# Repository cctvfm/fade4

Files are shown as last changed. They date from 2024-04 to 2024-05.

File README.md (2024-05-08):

# fade4
A performance MIDI and CV controller based on SAMD21G

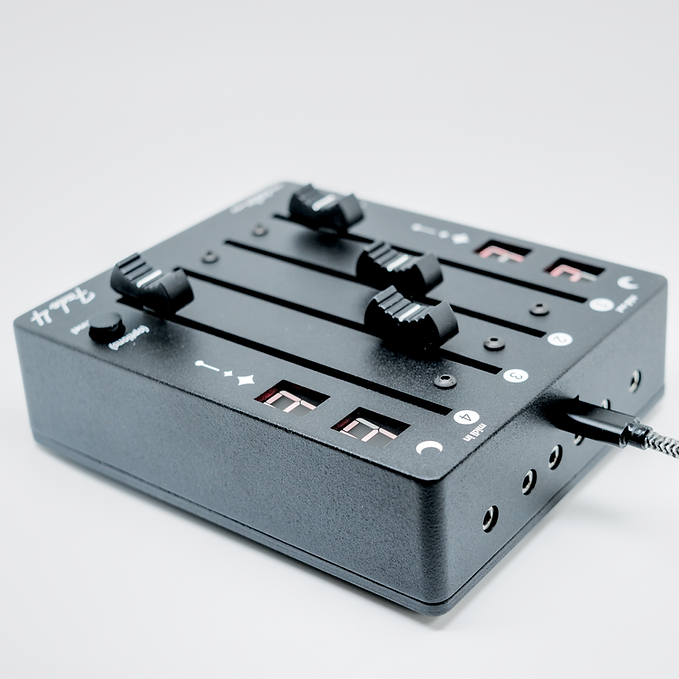
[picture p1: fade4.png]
Fade 4


Fade 4 runs on an Atmel SAMD21G microcontroller running the Feather M0 Bootloader. This allows Fade 4 to be developed on using the Arduino programming environment, and make use of Arduino libraries.

The SAMD21G handles all USB communication while using it's internal ADCs to read the positions of the faders. Each fader is connected between 0V and 3.3V, with the wiper providing a voltage between 0V and 3.3V. An opamp is used to multiply this voltage by 1.5x to provide 0 to 5V to the CV outputs. The fader position is sampled through Responsive Analog Read to smooth out any jumpiness in the measurement.

MIDI is handled using the Forty Seven Effects MIDI Library, making sending MIDI and USB MIDI the simplest part of this device.

The 7 segment LED displays are of the common cathode type, meaning the 7 LEDs in the character have their anodes broken out to individual pins, while the cathodes are grouped together into one pin. I use a 2N3904 transistor connected to this cathode pin to enable the digit, allowing the 4 digits to share character pins, as long as each has its own transistor and cathode pin. 

These displays need to be enabled one at a time, and using persistence of vision it appears that the 4 digits are on all the time. The timing of these characters is handled by TC3, triggering an interrupt to turn the current LED charactor off, reconfigure the pins, and turn the next one on.

A second timer, TC0, is used to generate a PWM signal on the 4 cathode transistor pins. This PWM signal can be changed to adjust the brightness of the display from 0 to 100%.

_FIRMWARE UPDATE_

1) Download the .UF2 file for the new firmware

2) Remove the 4 screws on the bottom of Fade 4, and remove the cover.

3) Plug Fade 4 into your computer using  a USB-C cable. Mac or Windows or Linux, doesn't matter. It will show up as a MIDI device named "Fade 4".

4) Double tap the button on the PCB marked "RESET". Two quick presses. A USB drive will appear on your computer, labelled "FEATHER" or "FEATHERBOOT"

5) Copy and paste the UF2 file into the USB drive. If prompted to overwrite, select YES.

6) Unplug, and reinstall the bottom cover. The firmware has been updated.

_HACKING_

You just need the .ino file in a folder named the same as it. Arduino or Arduino IDE, but you will need the following packages:

Adafruit SAMD Board Package
Flash Storage
Responsive Analog Read
MIDI

All firmware updates can be done over the USB C port. The 4 pin header is just for initial bootloader burn using an SWD programmer.

*November 2023:* 5 units built for testing. These are V1.0 units. They have an issue where the ADC is referenced to 5V and not 3.3V, so depending on USB power supply, the faders may not reach all the way to 127. fade4.ino.feather_m0-MAX975.uf2 provided as a fix for these units.

*April 15 2024:* Initial kit run. V1.1 released, fixes above issue. Build guide published to cctv.fm/fade4. Shipped with V1.1 preflashed.

*April 17 2023:* Bug fix, channels via TRS do not match channels via USB. Due to USB library counting channels from 0 and MIDI library counting from 1.

*May 8 2024:* Chris found a bug causing Program Changes to not function at all on V12, added bounds checking to message types.

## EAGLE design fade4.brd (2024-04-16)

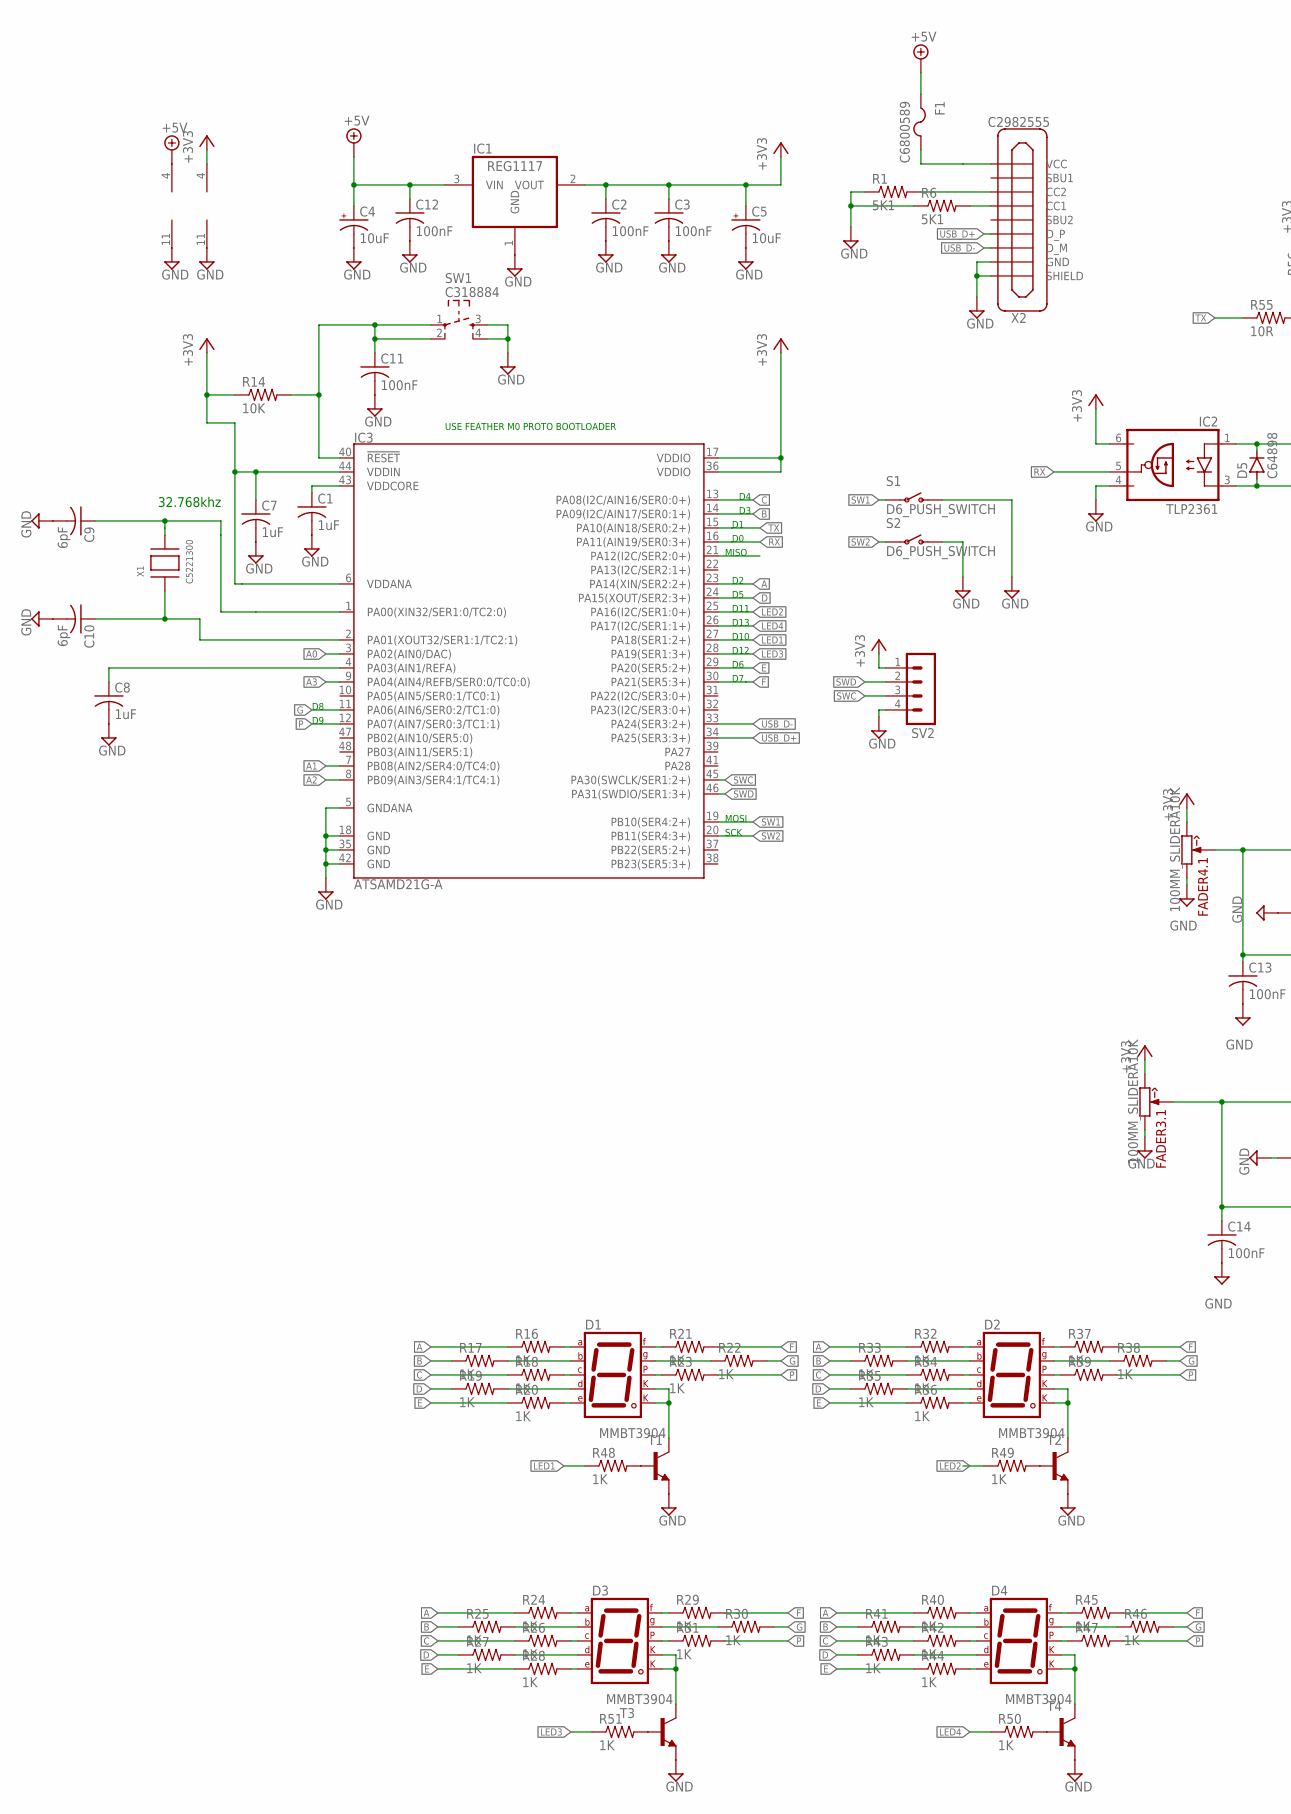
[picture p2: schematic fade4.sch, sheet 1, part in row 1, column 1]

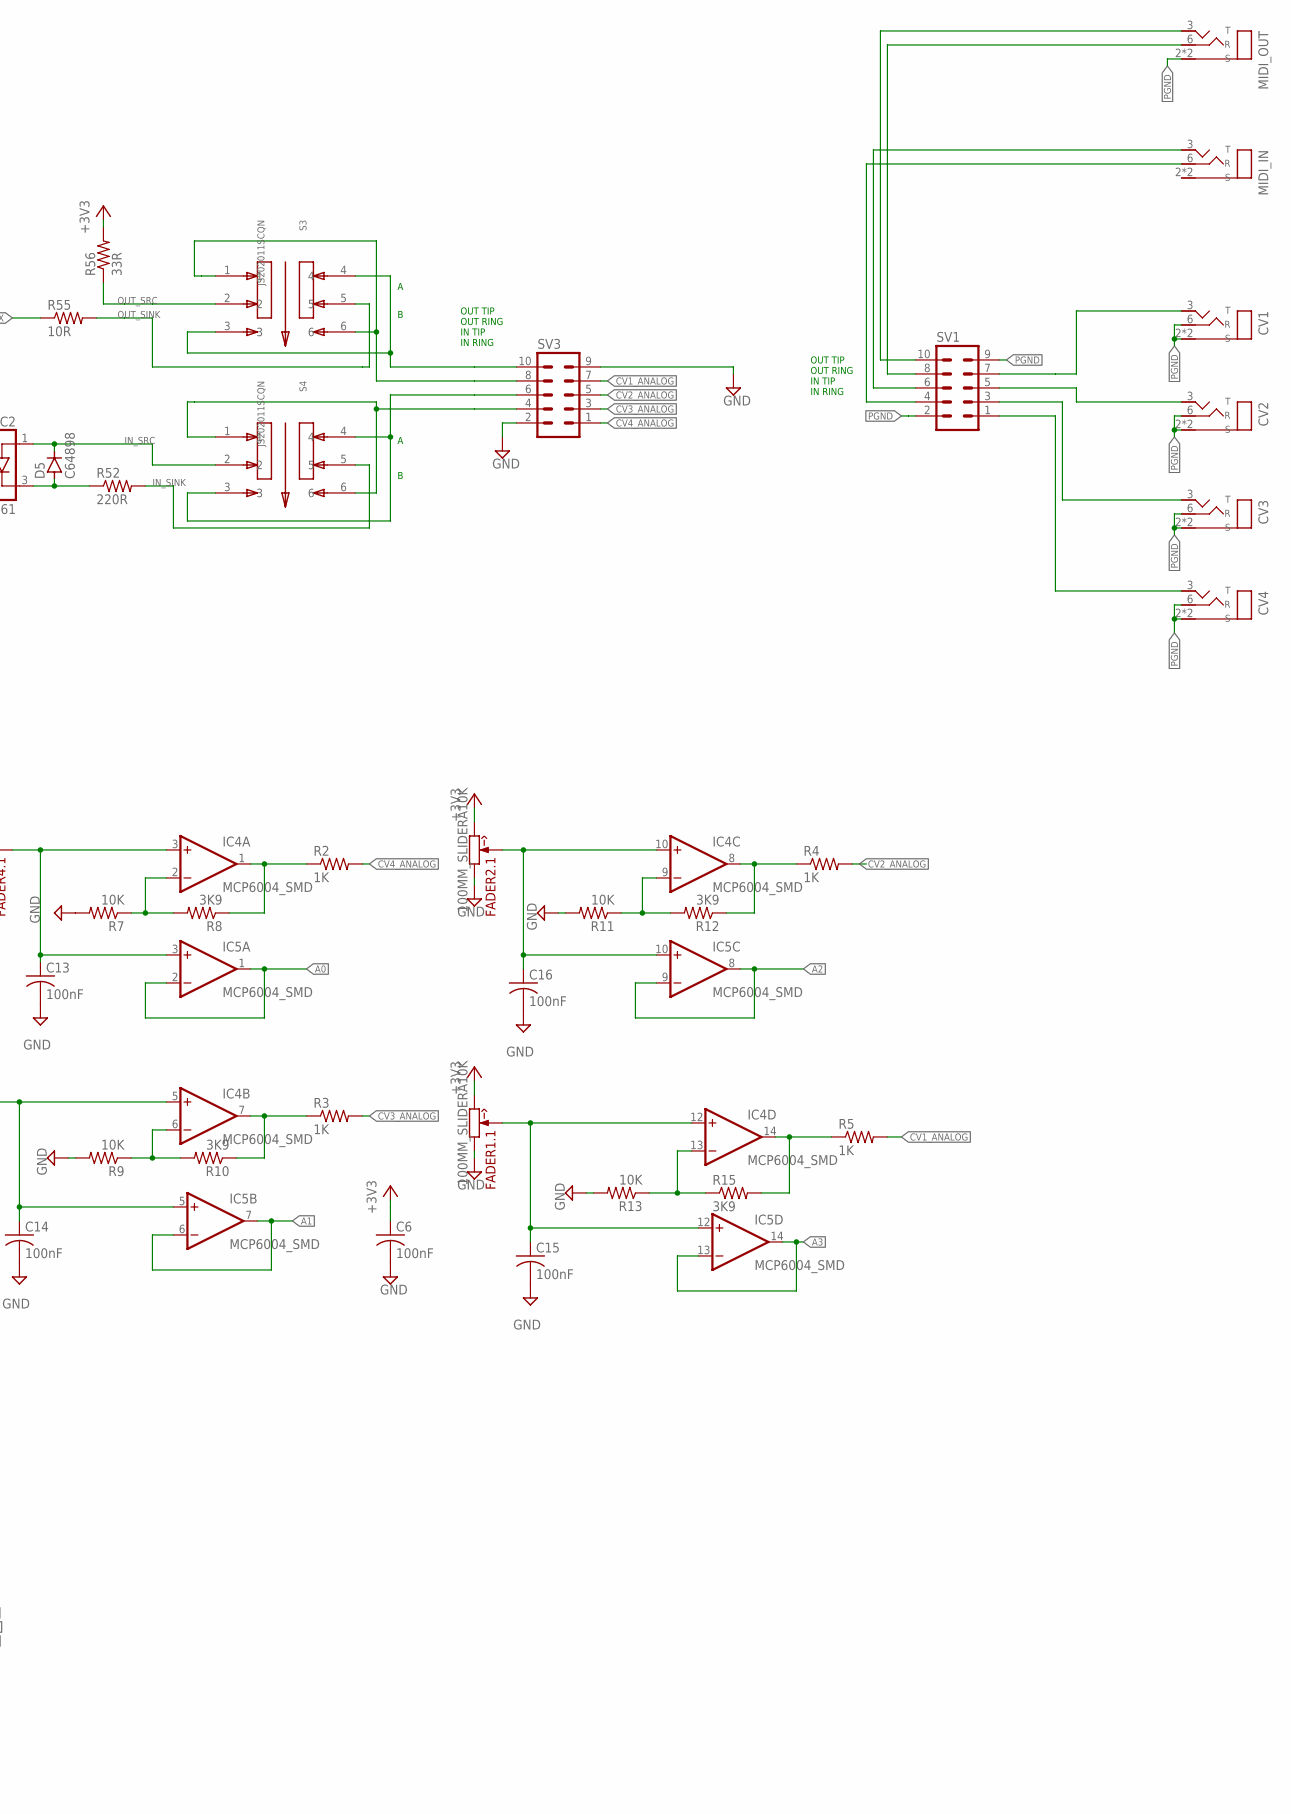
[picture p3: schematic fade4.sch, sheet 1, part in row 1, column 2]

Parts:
C1, C7, C8: 1uF; C0603K
C2, C3, C6, C11, C12, C13, C14, C15, C16: 100nF; C0603K
C4, C5: 10uF; A/3216-18R
C9, C10: 6pF; C0603K
CV1, CV2, CV3, CV4: C725772
D1, D2, D3, D4: 7SEG-CK; 7SEG-13
D5: C64898; SOD123
F1: C6800589; R1206
FADER1, FADER2, FADER3, FADER4: 100MM_SLIDERA10K; 100MM-SLIDER
IC1: REG1117; SOT223
IC2: TLP2361; SOIC-5
IC3: ATSAMD21G-A; TQFP-48
IC4, IC5: MCP6004_SMD; SO14
MIDI_IN: C725772
MIDI_OUT: C725772
R1, R6: 5K1; R0603
R2, R3, R4, R5, R16, R17, R18, R19, R20, R21, R22, R23, R24, R25, R26, R27, R28, R29, R30, R31, R32, R33, R34, R35, R36, R37, R38, R39, R40, R41, R42, R43, R44, R45, R46, R47, R48, R49, R50, R51: 1K; R0603
R7, R9, R11, R13, R14: 10K; R0603
R8, R10, R12, R15: 3K9; R0603
R52: 220R; R0603
R55: 10R; R1206
R56: 33R; R1206
S1, S2: D6_PUSH_SWITCH
S3, S4: JS202011SCQN; SW_JS202011SCQN
SV1, SV3: MA05-2
SV2: MA04-1
SW1: C318884; SW_TACT_SMALL
T1, T2, T3, T4: MMBT3904; SOT23-BEC
X1: C5221300; XTAL3215
X2: C2982555

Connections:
+3V3: C2.1, C3.1, C5.+, C6.1, C7.1, FADER1.A3 (CW), FADER2.A3 (CW), FADER3.A3 (CW), FADER4.A3 (CW), IC1.2 (VOUT), IC2.6 (VCC), IC3.6 (VDDANA), IC3.17 (VDDIO), IC3.36 (VDDIO), IC3.44 (VDDIN), IC5.4 (V+), R14.1, R56.2, SV2.1
+5V: C4.+, C12.1, F1.1, IC1.3 (VIN), IC4.4 (V+)
A: IC3.23 (PA14(XIN/SER2:2+)), R16.1, R24.1, R32.1, R40.1
A0: IC3.3 (PA02(AIN0/DAC)), IC5.1 (OUT), IC5.2 (-IN)
A1: IC3.7 (PB08(AIN2/SER4:0/TC4:0)), IC5.6 (-IN), IC5.7 (OUT)
A2: IC3.8 (PB09(AIN3/SER4:1/TC4:1)), IC5.8 (OUT), IC5.9 (-IN)
A3: IC3.9 (PA04(AIN4/REFB/SER0:0/TC0:0)), IC5.13 (-IN), IC5.14 (OUT)
B: IC3.14 (PA09(I2C/AIN17/SER0:1+)), R17.1, R25.1, R33.1, R41.1
C: IC3.13 (PA08(I2C/AIN16/SER0:0+)), R18.1, R26.1, R34.1, R42.1
CV1_ANALOG: R5.2, SV3.7
CV2_ANALOG: R4.2, SV3.5
CV3_ANALOG: R3.2, SV3.3
CV4_ANALOG: R2.2, SV3.1
D: IC3.24 (PA15(XOUT/SER2:3+)), R19.1, R27.1, R35.1, R43.1
E: IC3.29 (PA20(SER5:2+)), R20.1, R28.1, R36.1, R44.1
F: IC3.30 (PA21(SER5:3+)), R21.2, R29.2, R37.2, R45.2
G: IC3.11 (PA06(AIN6/SER0:2/TC1:0)), R22.2, R30.2, R38.2, R46.2
GND: C1.2, C2.2, C3.2, C4.-, C5.-, C6.2, C7.2, C8.2, C9.2, C10.2, C11.2, C12.2, C13.2, C14.2, C15.2, C16.2, FADER1.A1 (CCW), FADER2.A1 (CCW), FADER3.A1 (CCW), FADER4.A1 (CCW), IC1.1 (GND), IC2.4 (GND), IC3.5 (GNDANA), IC3.18 (GND), IC3.35 (GND), IC3.42 (GND), IC4.11 (V-), IC5.11 (V-), R1.1, R6.1, R7.2, R9.2, R11.2, R13.2, S1.P$1 (O), S1.P$2 (O), S2.P$1 (O), S2.P$2 (O), SV2.4, SV3.2, SV3.9, SW1.3, SW1.4, T1.E, T2.E, T3.E, T4.E, X2.A12B1 (GND), X2.B12A1 (GND), X2.SHIELD1 (SHIELD), X2.SHIELD2 (SHIELD), X2.SHIELD3 (SHIELD), X2.SHIELD4 (SHIELD)
IN_RING: S4.1, S4.6, SV3.4
IN_SINK: R52.2, S4.5
IN_SRC: D5.1 (C), IC2.1 (A), S4.2
IN_TIP: S4.3, S4.4, SV3.6
LED1: IC3.27 (PA18(SER1:2+)), R48.1
LED2: IC3.25 (PA16(I2C/SER1:0+)), R49.1
LED3: IC3.28 (PA19(SER1:3+)), R51.1
LED4: IC3.26 (PA17(I2C/SER1:1+)), R50.1
unnamed: R6.2, X2.A5 (CC1)
unnamed: R1.2, X2.B5 (CC2)
unnamed: C1.1, IC3.43 (VDDCORE)
unnamed: F1.2, X2.A9B4 (VCC), X2.B9A4 (VCC)
unnamed: C13.1, FADER4.A2 (W), IC4.3 (+IN), IC5.3 (+IN)
unnamed: C14.1, FADER3.A2 (W), IC4.5 (+IN), IC5.5 (+IN)
unnamed: C16.1, FADER2.A2 (W), IC4.10 (+IN), IC5.10 (+IN)
unnamed: C15.1, FADER1.A2 (W), IC4.12 (+IN), IC5.12 (+IN)
unnamed: IC4.1 (OUT), R2.1, R8.1
unnamed: IC4.7 (OUT), R3.1, R10.1
unnamed: IC4.8 (OUT), R4.1, R12.1
unnamed: IC4.14 (OUT), R5.1, R15.2
unnamed: D1.7 (A), R16.2
unnamed: IC4.9 (-IN), R11.1, R12.2
unnamed: D1.6 (B), R17.2
unnamed: IC4.13 (-IN), R13.1, R15.1
unnamed: CV1.3 (T), SV1.7
unnamed: IC4.6 (-IN), R9.1, R10.2
unnamed: D1.4 (C), R18.2
unnamed: D1.2 (D), R19.2
unnamed: D1.1 (E), R20.2
unnamed: D3.7 (A), R24.2
unnamed: D3.6 (B), R25.2
unnamed: D3.4 (C), R26.2
unnamed: D3.2 (D), R27.2
unnamed: D1.9 (F), R21.1
unnamed: D1.10 (G), R22.1
unnamed: D1.5 (DP), R23.1
unnamed: D5.2 (A), IC2.3 (C), R52.1
unnamed: D3.1 (E), R28.2
unnamed: D3.9 (F), R29.1
unnamed: D3.10 (G), R30.1
unnamed: D3.5 (DP), R31.1
unnamed: D2.7 (A), R32.2
unnamed: D2.6 (B), R33.2
unnamed: D2.4 (C), R34.2
unnamed: D2.2 (D), R35.2
unnamed: D2.1 (E), R36.2
unnamed: D2.9 (F), R37.1
unnamed: C8.1, IC3.4 (PA03(AIN1/REFA))
unnamed: C9.1, IC3.1 (PA00(XIN32/SER1:0/TC2:0)), X1.P$2
unnamed: C10.1, IC3.2 (PA01(XOUT32/SER1:1/TC2:1)), X1.P$1
unnamed: D2.10 (G), R38.1
unnamed: D2.5 (DP), R39.1
unnamed: D4.7 (A), R40.2
unnamed: D4.6 (B), R41.2
unnamed: D4.4 (C), R42.2
unnamed: D4.2 (D), R43.2
unnamed: D4.1 (E), R44.2
unnamed: D4.9 (F), R45.1
unnamed: D4.10 (G), R46.1
unnamed: D4.5 (DP), R47.1
unnamed: CV2.3 (T), SV1.5
unnamed: CV3.3 (T), SV1.3
unnamed: CV4.3 (T), SV1.1
unnamed: MIDI_OUT.3 (T), SV1.10
unnamed: MIDI_OUT.6 (R), SV1.8
unnamed: MIDI_IN.3 (T), SV1.6
unnamed: MIDI_IN.6 (R), SV1.4
unnamed: R48.2, T1.B
unnamed: R49.2, T2.B
unnamed: R50.2, T4.B
unnamed: R51.2, T3.B
unnamed: IC4.2 (-IN), R7.1, R8.2
unnamed: D3.3 (CK1), D3.8 (CK2), T3.C
unnamed: D4.3 (CK1), D4.8 (CK2), T4.C
unnamed: D2.3 (CK1), D2.8 (CK2), T2.C
unnamed: D1.3 (CK1), D1.8 (CK2), T1.C
OUT_RING: S3.1, S3.6, SV3.8
OUT_SINK: R55.2, S3.5
OUT_SRC: R56.1, S3.2
OUT_TIP: S3.3, S3.4, SV3.10
P: IC3.12 (PA07(AIN7/SER0:3/TC1:1)), R23.2, R31.2, R39.2, R47.2
PGND: CV1.2 (S), CV1.5 (S), CV1.6 (R), CV2.2 (S), CV2.5 (S), CV2.6 (R), CV3.2 (S), CV3.5 (S), CV3.6 (R), CV4.2 (S), CV4.5 (S), CV4.6 (R), MIDI_OUT.2 (S), MIDI_OUT.5 (S), SV1.2, SV1.9
RST_PCB: C11.1, IC3.40 (!RESET!), R14.2, SW1.1, SW1.2
RX: IC2.5 (VO), IC3.16 (PA11(AIN19/SER0:3+))
SW1: IC3.19 (PB10(SER4:2+)), S1.P$3, S1.P$4
SW2: IC3.20 (PB11(SER4:3+)), S2.P$3, S2.P$4
SWC: IC3.45 (PA30(SWCLK/SER1:2+)), SV2.3
SWD: IC3.46 (PA31(SWDIO/SER1:3+)), SV2.2
TX: IC3.15 (PA10(AIN18/SER0:2+)), R55.1
USB_D+: IC3.34 (PA25(SER3:3+)), X2.A6 (D_P), X2.B6 (D_P)
USB_D-: IC3.33 (PA24(SER3:2+)), X2.A7 (D_M), X2.B7 (D_M)

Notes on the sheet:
32.768khz
USE FEATHER M0 PROTO BOOTLOADER
D10
D11
D12
D13
MOSI
SCK
MISO
OUT TIP OUT RING IN TIP IN RING

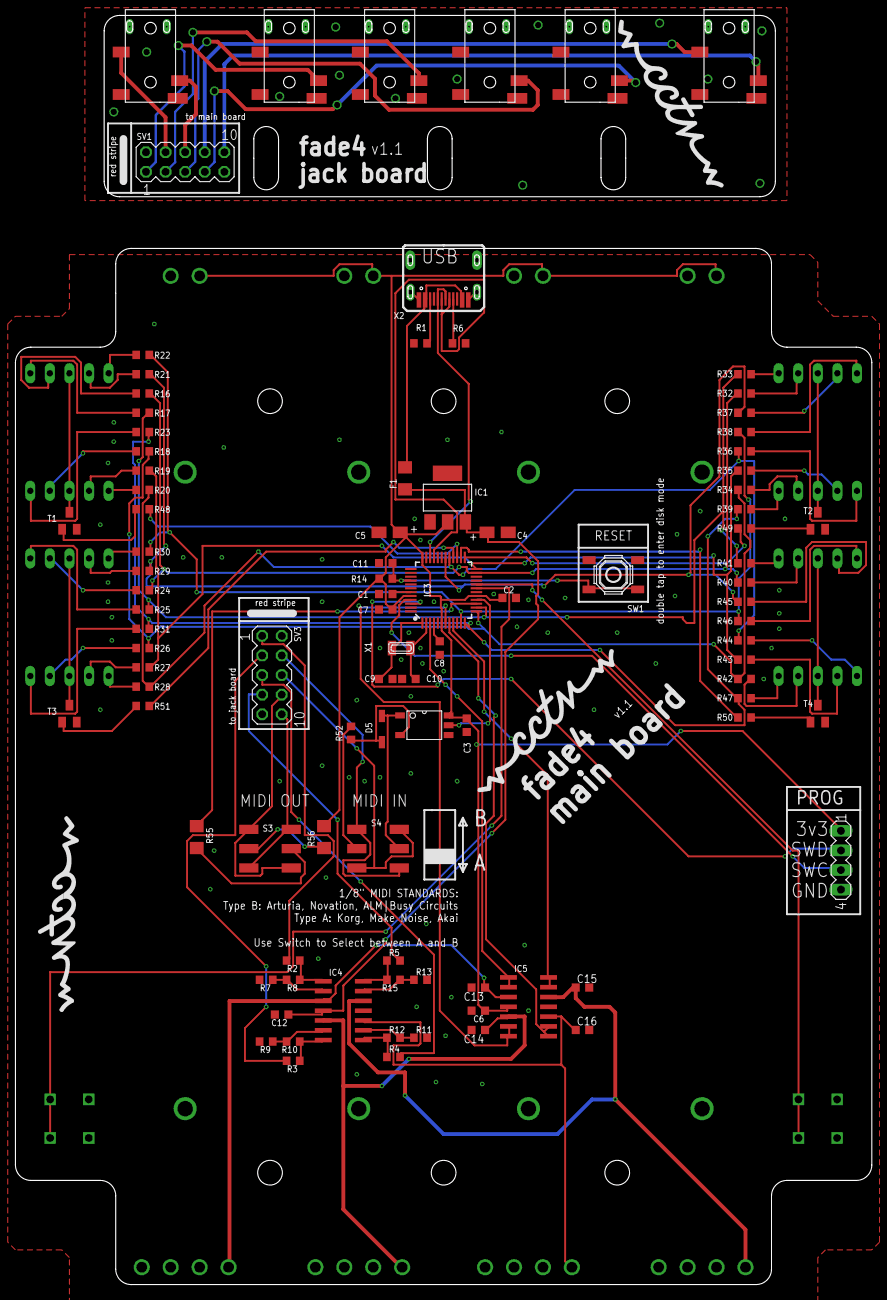
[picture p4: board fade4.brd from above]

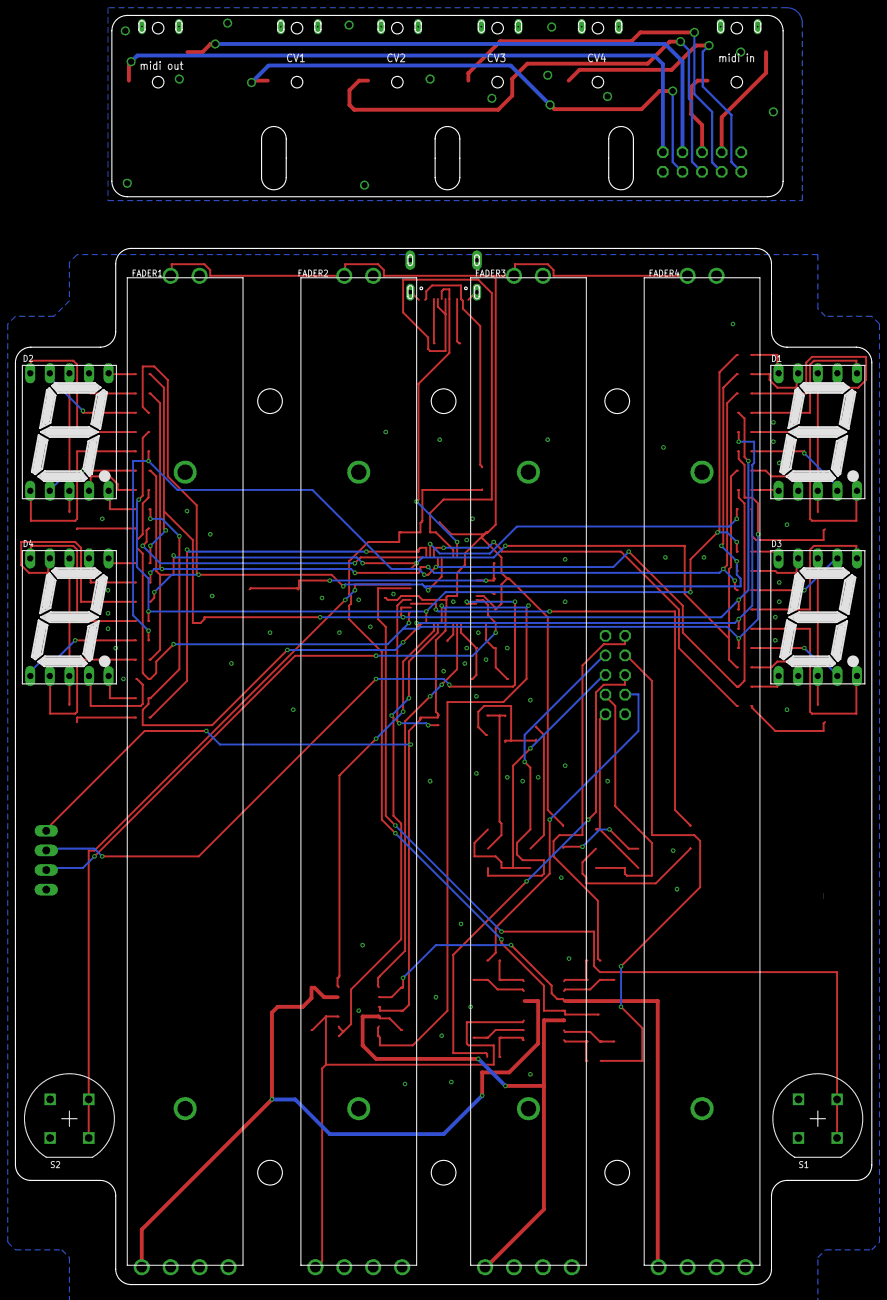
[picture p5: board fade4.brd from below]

Board: 2 copper layers, 111.0 x 134.3 mm, 105 parts (10 on the bottom side), 109 nets.

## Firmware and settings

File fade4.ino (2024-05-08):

#include <FlashAsEEPROM.h>
#include <FlashStorage.h>
#include <MIDI.h>
#include <ResponsiveAnalogRead.h>
#include <MIDIUSB.h>


#define MAXPOTVALUE 1015  //Change this to a lower value on V1 boards with certain power supplies (<5V)
//for example:
//#define MAXPOTVALUE 975

#define CPU_HZ 48000000
#define TIMER_PRESCALER_DIV 1024

void startTimer(int frequencyHz);
void setTimerFrequency(int frequencyHz);
void TC3_Handler();

MIDI_CREATE_DEFAULT_INSTANCE();

#define POT4 A0 //pcb pots are backwards on V1.0
#define POT3 A1
#define POT2 A2
#define POT1 A3

#define DIGIT1 11 //PA16  TCC0/WO[6] F
#define DIGIT2 10 //PA18  TCC0/WO[2] F
#define DIGIT3 13 //PA17  TCC0/WO[7] F
#define DIGIT4 12 //PA19  TCC0/WO[3] F

#define SW2 MOSI
#define SW1 SCK

#define SEG_A 2
#define SEG_B 3
#define SEG_C 4
#define SEG_D 5
#define SEG_E 6
#define SEG_F 7
#define SEG_G 8
#define SEG_P 9

#define NUMBER 0
#define LETTER 1
#define RAW 2
#define HEX 16

unsigned char segments[]={SEG_A,SEG_B,SEG_C,SEG_D,SEG_E,SEG_F,SEG_G,SEG_P};
unsigned char digits[]={DIGIT1, DIGIT2, DIGIT3, DIGIT4};

unsigned char LEDchars[4];
unsigned int LEDbrightness = 60;
unsigned int currentbrightness = 60;

unsigned long int lastLEDUpdate = 0;

#define SMOOTHNESS 0.004

ResponsiveAnalogRead analogPOTS[4] = {
    ResponsiveAnalogRead(POT1, true, SMOOTHNESS),
    ResponsiveAnalogRead(POT2, true, SMOOTHNESS),
    ResponsiveAnalogRead(POT3, true, SMOOTHNESS),
    ResponsiveAnalogRead(POT4, true, SMOOTHNESS)
};

FlashStorage(flash_valid, bool);
FlashStorage(saved_brightness,unsigned char);

FlashStorage(saved_message1,unsigned char);
FlashStorage(saved_message2,unsigned char);
FlashStorage(saved_message3,unsigned char);
FlashStorage(saved_message4,unsigned char);

FlashStorage(saved_channel1,unsigned char);
FlashStorage(saved_channel2,unsigned char);
FlashStorage(saved_channel3,unsigned char);
FlashStorage(saved_channel4,unsigned char);


unsigned int potvalues[4];
unsigned char ccvalues[4]={0,0,0,0};

bool saveDataFlag = 0;
unsigned long int saveDataTime = 0;

void setup() {
  // put your setup code here, to run once:



  pinMode(POT1, INPUT);
  pinMode(POT2, INPUT);
  pinMode(POT3, INPUT);
  pinMode(POT4, INPUT);

  randomSeed(analogRead(POT1)); //used for boot animation
  
  pinMode(DIGIT1, OUTPUT);
  pinMode(DIGIT2, INPUT);
  pinMode(DIGIT3, INPUT);
  pinMode(DIGIT4, INPUT);

  setupTCC0();



  pinMode(SW1, INPUT_PULLUP);
  pinMode(SW2, INPUT_PULLUP);
  pinMode(SEG_A, OUTPUT);
  pinMode(SEG_B, OUTPUT);
  pinMode(SEG_C, OUTPUT);
  pinMode(SEG_D, OUTPUT);
  pinMode(SEG_E, OUTPUT);
  pinMode(SEG_F, OUTPUT);
  pinMode(SEG_G, OUTPUT);
  pinMode(SEG_P, OUTPUT);



 
  analogPOTS[0].enableEdgeSnap();
  analogPOTS[1].enableEdgeSnap();
  analogPOTS[2].enableEdgeSnap();
  analogPOTS[3].enableEdgeSnap();
  

  
  //Serial.begin(9600);
  startTimer(400);  //start interrupt for LED characters
  MIDI.begin(MIDI_CHANNEL_OMNI);
  MIDI.turnThruOn();
  welcome();

  loadData();
}

#define FALSE 0
#define TRUE 1
unsigned char channels[4]= {1,1,1,1};
unsigned char messages[4] = {1,11,71,74};
unsigned char options[4] = {60,1,1,1};

#define NORMAL 0
#define SET_MESSAGE 1
#define SET_CHANNEL 2
#define SET_OPTIONS 3
bool fadeout = 0;
unsigned char state = 0;
void loop() {
  //THE MAIN LOOP HERE

  static unsigned long fadeouttime = 0;
  static unsigned long lastupdate = 0;


  if((millis()-lastupdate) > 20)
  {
    update_all();
    lastupdate = millis();
  }

  MIDI.read();

  if(fadeout == 1)  //if we're in fadeout mode (==1)
  {
    if(millis()-fadeouttime > 10)//and 10 ms has elapsed since the last time we did this
    {
      fadeouttime = millis(); //catch the new time of the fade loop
      
      if(currentbrightness == 0)  //if we're at 0
      {
        fadeout = 2;
      }
      else
        reducebrightness(); //reduce the brightness by x
    }
  }




  if((millis()-lastLEDUpdate) > 3000 && (fadeout == 0))
  {
    //if the LEDs have been on for more than 4 seconds, clear them
    if(state == NORMAL) // if we're in normal operation
    { 
      //clearLED();
      fadeout=1;
      fadeouttime=millis();
      currentbrightness = LEDbrightness;
    }

    else
    {
        //keep the displays on if we're in Channel/Message/Options mode

    }
  }
  
  if(saveDataFlag == 1)
  {
    if(millis()-saveDataTime > 10000)
    {
        //only write to eeprom every 10 seconds and only if something has changed
        saveData();
        saveDataFlag = 0;
    }
  }
  //delay(20);
    
}

void update_all (void)
{

  #define BUTTONHOLDTIME 1000
  #define DEBOUNCETIME 10

  unsigned char temp;
  unsigned char x;
  int y;
  static unsigned char update[4] = {FALSE,FALSE,FALSE,FALSE};
  static unsigned int buttonpressedtime[3];
  static bool buttonpressed[3];
  if((digitalRead(SW1) == 0) && (digitalRead(SW2)==1))  //Sw1 is low but sw2 is not
  {
      
      if(buttonpressed[0]==1 && state != SET_MESSAGE) //it was previously pressed
      {
          if((millis()-buttonpressedtime[0]) > BUTTONHOLDTIME)  //have we waited long enough?
          {
            //yes, set the state
            state = SET_MESSAGE;
            clearLED();  //we're in the set message mode
            LEDchars[0]=charactertoLED('E',LETTER,0);
            LEDchars[1]=charactertoLED('I',LETTER,0);
            LEDchars[2]=charactertoLED('D',LETTER,0);
            LEDchars[3]=charactertoLED('T',LETTER,1);
            delay(100);

            
          }

      }
      else if(buttonpressed[0] == 0)  //first time pressed
      {
        buttonpressedtime[0]= millis(); //save the time it was pressed
        buttonpressed[0]=1;
      }
  }

  else if ((digitalRead(SW1) == 1) && (digitalRead(SW2)==0))  //button two pressed
  {
      if(buttonpressed[1]==1 && state != SET_CHANNEL) //it was previously pressed
      {
          if((millis()-buttonpressedtime[1]) > BUTTONHOLDTIME)  //have we waited long enough?
          {
            //yes, set the state
            state = SET_CHANNEL;
            clearLED();  //we're in the set message mode
            LEDchars[0]=charactertoLED('C',LETTER,0);
            LEDchars[1]=charactertoLED('A',LETTER,0);
            LEDchars[2]=charactertoLED('H',LETTER,0);
            LEDchars[3]=charactertoLED('N',LETTER,1);
            delay(100);

            
          }

      }
      else if(buttonpressed[1] == 0)  //first time pressed
      {
        buttonpressedtime[1]= millis(); //save the time it was pressed
        buttonpressed[1]=1;
      }
  }
  else if ((digitalRead(SW1) == 0) && (digitalRead(SW2)==0))  //BOTH BUTTONS PRESSED
  {
    if(buttonpressed[2]==1 && state != SET_OPTIONS) //it was previously pressed
      {
          if((millis()-buttonpressedtime[2]) > BUTTONHOLDTIME)  //have we waited long enough? Double time for options menu
          {
            //yes, set the state
            state = SET_OPTIONS;
            clearLED();  //we're in the set message mode
            LEDchars[0]=charactertoLED('O',LETTER,0);
            LEDchars[1]=charactertoLED('T',LETTER,0);
            LEDchars[2]=charactertoLED('P',LETTER,0);
            LEDchars[3]=charactertoLED('N',LETTER,1);
            delay(200);

            
          }

      }
      else if(buttonpressed[2] == 0)  //first time pressed
      {
        buttonpressedtime[2]= millis(); //save the time it was pressed
        buttonpressed[2]=1;
      }
  }

  else if((digitalRead(SW1)==1) && (digitalRead(SW2)==1))  //neither button pressed
  {
    if(buttonpressed[0] == 1) //button was previously pressed, but now it isn't
    {
      if((millis() - buttonpressedtime[0]) > DEBOUNCETIME)
      {
        //only clear the flag if we're out of the debounce window
        buttonpressed[0]=0;
        if(state ==SET_MESSAGE)
        {
          state=NORMAL;
          clearLED(); 
          delay(100);
          //Save Settings here!!!  <------------------------
        }
      }
    }
    if(buttonpressed[1] == 1) //button was previously pressed, but now it isn't
    {
      if((millis() - buttonpressedtime[1]) > DEBOUNCETIME)
      {
        //only clear the flag if we're out of the debounce window
        buttonpressed[1]=0;
        if(state == SET_CHANNEL)
        {
          state=NORMAL;
          clearLED(); 
          delay(100);
          //Save Settings here!!!  <------------------------
        }
      }
    }
    if(buttonpressed[2] == 1) //button was previously pressed, but now it isn't
    {
      if((millis() - buttonpressedtime[2]) > DEBOUNCETIME)
      {
        //only clear the flag if we're out of the debounce window
        buttonpressed[2]=0;
        if(state == SET_OPTIONS)
        {
          state=NORMAL;
          clearLED(); 
          delay(100);
          //Save Settings here!!!  <------------------------
        }
      }
    }
  }

  //THE POT READING PART
  for (x=0;x<4;x++)
  {
    analogPOTS[x].update();
    if(analogPOTS[x].hasChanged()) {
      potvalues[x]=analogPOTS[x].getValue();
      if(state==NORMAL)
        update[x]=TRUE;

      if(state == SET_MESSAGE)
      {
        messages[x]= map(potvalues[x],0,MAXPOTVALUE,0,129);
        if(messages[x]>129)
          messages[x]=129;
        //we're in the SET_MESSAGE MODE, so movement of the fader sets a new message
        //display the current value on the LEDs
        if(messages[x]<=127)  //standard CC
        {
          LEDchars[0]=charactertoLED(x+1,NUMBER,0);
          LEDchars[1]=charactertoLED((messages[x]%100)/10,NUMBER,0);
          LEDchars[2]=charactertoLED(messages[x]/100,NUMBER,0);
          LEDchars[3]=charactertoLED(messages[x]%10, NUMBER,1);
        }
        else if(messages[x]==128) //Pitch Bend
        {
          
          LEDchars[0]=charactertoLED(x+1,NUMBER,0);
          LEDchars[1]=charactertoLED('P',LETTER,0);
          LEDchars[2]=charactertoLED(0,RAW,0);
          LEDchars[3]=charactertoLED('B', LETTER,1);
        }
        else if(messages[x]==129) //Program Change
        {
          
          LEDchars[0]=charactertoLED(x+1,NUMBER,0);
          LEDchars[1]=charactertoLED('P',LETTER,0);
          LEDchars[2]=charactertoLED(0,RAW,0);
          LEDchars[3]=charactertoLED('C', LETTER,1);
        }
        saveDataFlag = 1; //mark the flag so we save the data
      }
      
      else if(state == SET_CHANNEL)
      {
        channels[x]= map(potvalues[x],0,MAXPOTVALUE,0,15);
        if(channels[x]>15)
          channels[x] = 15;
        //we're in the SET_CHANNEL MODE, so movement of the fader sets a new message
        //display the current value on the LEDs

        LEDchars[0]=charactertoLED(x+1,NUMBER,0);
        LEDchars[1]=charactertoLED(((channels[x]+1)%100)/10,NUMBER,0);
        LEDchars[2]=charactertoLED(0,RAW,0);
        LEDchars[3]=charactertoLED((channels[x]+1)%10, NUMBER,0);
        saveDataFlag = 1;

      }

      else if(state == SET_OPTIONS)
      {
        if(x==0)
        {
          
          options[x]= map(potvalues[x],0,MAXPOTVALUE,10,99);
          if(options[x]>99)
            options[x] = 99;
          LEDchars[0]=charactertoLED('B',LETTER,0);
          LEDchars[1]=charactertoLED((options[x]%100)/10,NUMBER,0);
          LEDchars[2]=charactertoLED(0,RAW,0);
          LEDchars[3]=charactertoLED(options[x]%10, NUMBER,0);
        }
        updateOptions();
        saveDataFlag = 1;
      }
      
    }
  }

  for (x=0;x<4;x++)
  {
    if(update[x]==TRUE)
    {
      update[x]=FALSE;
      
      sendMIDI(potvalues[x],channels[x],messages[x],x);
    }
  }
}
bool firstbootread[4]={1,1,1,1};
unsigned int lastdata[4]={0,0,0,0};
void sendMIDI (unsigned int data, unsigned char channel, unsigned char message, unsigned char lane)
{
  unsigned char temp;
  if((message >=0) && (message<=127)) //standard midi CC
  {
    //data = constrain(data,25,1010);
    //temp=map(data,25,1010,0,127);
    //temp = constrain(data,0,MAXPOTVALUE);
    temp = map(data,0,MAXPOTVALUE, 0, 127);
    if(temp>127)
      temp = 127;
    if(firstbootread[lane])
    {
      lastdata[lane]=temp;
      firstbootread[lane]=0;
    }
    if(temp!=lastdata[lane])
    {
      //create midi message here
      /*
      Serial.print("lane: ");
      Serial.print(lane);
      Serial.print(" channel: ");
      Serial.print(channel);
      Serial.print(" CC: ");
      Serial.print(message);
      Serial.print(" data: ");
      Serial.print(temp);
      Serial.print(" raw: ");
      Serial.println(data);
      Serial.println("");
      */
      lastdata[lane]=temp;
      LEDchars[0]=charactertoLED('C',LETTER,0);
      LEDchars[1]=charactertoLED((temp%100)/10,NUMBER,0);
      LEDchars[2]=charactertoLED(temp/100,NUMBER,0);
      LEDchars[3]=charactertoLED(temp%10, NUMBER,0);

      

        MIDI.sendControlChange(message, temp, channel+1);
        midiEventPacket_t event = {0x0B, (uint8_t)(0xB0 | channel), message, temp};
        MidiUSB.sendMIDI(event);
        MidiUSB.flush();

    }    
    else
    {
      //Serial.print(".");  //for debugging only
      //Serial.println(lastdata[lane]);
    }

  }
  else if(message == 128) //Pitch Bend
  { //wide range, 14 bit?
    int pbval;
    pbval = data<<4;

    if(firstbootread[lane])
    {
      lastdata[lane]=pbval;
      firstbootread[lane]=0;
    }
    if(pbval!=lastdata[lane])
    {
      lastdata[lane]=pbval;
      midiEventPacket_t event = {0x0E, (uint8_t)(0xE0 | channel), (uint8_t)(data>>8), (uint8_t)data};
      pbval = pbval - 8192;
  
      
      MIDI.sendPitchBend(pbval, channel+1);
      
      MidiUSB.sendMIDI(event);
      MidiUSB.flush();
  
      temp = data&0xFF;
      
      
      LEDchars[0]=charactertoLED('B',LETTER,0);
      LEDchars[1]=charactertoLED((data%256)/16,HEX,0);
      LEDchars[2]=charactertoLED(data/256,HEX,0);
      LEDchars[3]=charactertoLED(data%16, HEX,0);
    }
  }
  
  else if(message == 129) //Program Change
  {
    temp = map(data,0,MAXPOTVALUE, 0, 127);
    if(temp>127)
      temp = 127;


    if(firstbootread[lane])
    {
      lastdata[lane]=temp;
      firstbootread[lane]=0;
    }
    if(temp!=lastdata[lane])
    {
      lastdata[lane]=temp;
      MIDI.sendProgramChange(temp,channel+1);
      midiEventPacket_t event = {0x0C, (uint8_t)(0xC0 | channel), (uint8_t)(temp)};
      MidiUSB.sendMIDI(event);
      MidiUSB.flush();
  
       
  
      LEDchars[0]=charactertoLED('P',LETTER,0);
      LEDchars[1]=charactertoLED((temp%100)/10,NUMBER,0);
      LEDchars[2]=charactertoLED(temp/100,NUMBER,0);
      LEDchars[3]=charactertoLED(temp%10, NUMBER,0);
    }
  }
  
  else
    return;
    //invalid message type


}
unsigned char lastoptions[4];
void updateOptions (void)
{
  if(options[0] != lastoptions[0])
  { //update brightness
    LEDbrightness = options[0];
    REG_TCC0_CCB0 = LEDbrightness;
    lastoptions[0]=options[0];
  }

  
}
void clearLED (void)
{
  LEDchars[0] = 0;
  LEDchars[1] = 0;
  LEDchars[2] = 0;
  LEDchars[3] = 0;
}
void printLED (char digit)
{
  char x;
 
  
  PORT->Group[g_APinDescription[DIGIT1].ulPort].PINCFG[g_APinDescription[DIGIT1].ulPin].bit.PMUXEN = 0;
  PORT->Group[g_APinDescription[DIGIT2].ulPort].PINCFG[g_APinDescription[DIGIT2].ulPin].bit.PMUXEN = 0;
  PORT->Group[g_APinDescription[DIGIT3].ulPort].PINCFG[g_APinDescription[DIGIT3].ulPin].bit.PMUXEN = 0;
  PORT->Group[g_APinDescription[DIGIT4].ulPort].PINCFG[g_APinDescription[DIGIT4].ulPin].bit.PMUXEN = 0;
  
  for(x=0;x<8;x++)
  {
    if(((0x01 << x) & (LEDchars[digit])))
      digitalWrite(segments[x],HIGH);
    else
      digitalWrite(segments[x],LOW);
  }
  
  PORT->Group[g_APinDescription[digits[digit]].ulPort].PINCFG[g_APinDescription[digits[digit]].ulPin].bit.PMUXEN = 1;

  

}



unsigned char charactertoLED(unsigned char data, unsigned char type, bool decimal)
{
  char numbers[] = {
        B00111111,  //  0
        B00000110,  //  1
        B01011011,  //  2
        B01001111,  //  3
        B01100110,  //  4
        B01101101,  //  5
        B01111101,  //  6
        B00000111,  //  7
        B01111111,  //  8
        B01101111,  //  9        
    };
    char letters[] = {
        B01110111,  //  A
        B01111100,  //  B
        B01011000,  //  C
        B01011110,  //  D
        B01111001,  //  E
        B01110001,  //  F
        B00111101,  //  G
        B01110100,  //  H
        B00110000,  //  I
        B00011110,  //  J
        B00000000,  //  NO K
        B00111000,  //  L      
        B00000000,  // NO M
        B01010100,  // N
        B00111111,  // O
        B01110011,  // P  
        B01100111,  // Q  
        B01010000,  // r
        B01101101,  // S
        B01111000,  // t
        B00011100,  // u
        B00000000,  // no V
        B00000000,  // no W
        B00000000,  // no X
        B01101110,  // y
        B00000000   // no z        
    };


  lastLEDUpdate = millis();
  restorebrightness();
  switch (type){

    case NUMBER:
      if((data>=0) && (data<= 9))
      {
        if(decimal ==0)
          return numbers[data];
        else
          return (numbers[data]|B10000000);
      }
      break;
    case LETTER:
      if(data>='A' && (data<='Z'))
        return letters[(data-'A')];
      break;
    case RAW:
      return data;
      break;
    case HEX:
    {
      if((data>=0) && (data <=15))  //range 0-15 for a hex digit
      {
        if(data<10)
        {
          if(decimal == 0)
            return numbers[data];
          else
            return numbers[data]|B10000000;
        }
        else
        {
          if(decimal == 0)
            return letters[data-10];
          else
            return letters[data-10]|B10000000;
        }
      }
    }
  }

  
  return 0;
}

void welcome (void)
{
  unsigned char temp = 0;
  unsigned char x,y;
  unsigned int temp2;
  for (x=0;x<20;x++)
  {
    
    temp = 1<< random(7);
    LEDchars[0] = temp;
    temp = 1<<random(7);
    LEDchars[1] = temp;
    temp = 1<<random(7);
    LEDchars[2] = temp;
    temp = 1<<random(7);
    LEDchars[3] = temp;
    for(y=0;y<60;y++)
    {
      analogPOTS[0].update();
      temp2=analogPOTS[0].getValue();
      analogPOTS[1].update(); //update all faders so we don't jump at the start
      temp2=analogPOTS[1].getValue();
      analogPOTS[2].update();
      temp2=analogPOTS[2].getValue();
      analogPOTS[3].update();
      temp2=analogPOTS[3].getValue(); 
      delay(1);   
    }
  }

  clearLED();

  //Uncomment this section to test LED brightnesses
  //Used for matching LED display brightness (some are sometimes brighter than others?)
  /*
  LEDchars[0]  = charactertoLED(8,NUMBER,1);
  LEDchars[1]  = charactertoLED(8,NUMBER,1);
  LEDchars[2]  = charactertoLED(8,NUMBER,1);
  LEDchars[3]  = charactertoLED(8,NUMBER,1);
  delay(10);
  while(1);
  */
  //------------------------------------------------
}

// TIMER INTERRUPT STUFF HERE

unsigned long int lasttc3micros;
void TC3_Handler() {
  static char counter = 0;
  //TcCount16* TC = (TcCount16*) TC3;
  
  // If this interrupt is due to the compare register matching the timer count
  // we toggle the LED.
  if (TC3->COUNT16.INTFLAG.bit.MC0 == 1) {
    TC3->COUNT16.INTFLAG.bit.MC0 = 1;
    
      
    printLED(counter);
    counter++;
    if(counter>3)
    counter = 0;
  }

}

////////////////////////

void setTimerFrequency(int frequencyHz) {
  int compareValue = (CPU_HZ / (TIMER_PRESCALER_DIV * frequencyHz)) - 1;
  TcCount16* TC = (TcCount16*) TC3;
  // Make sure the count is in a proportional position to where it was
  // to prevent any jitter or disconnect when changing the compare value.
  TC->COUNT.reg = map(TC->COUNT.reg, 0, TC->CC[0].reg, 0, compareValue);
  TC->CC[0].reg = compareValue;
  //Serial.println(TC->COUNT.reg);
  //Serial.println(TC->CC[0].reg);
  while (TC->STATUS.bit.SYNCBUSY == 1);
}

void startTimer(int frequencyHz) {
  REG_GCLK_CLKCTRL = (uint16_t) (GCLK_CLKCTRL_CLKEN | GCLK_CLKCTRL_GEN_GCLK0 | GCLK_CLKCTRL_ID_TCC2_TC3) ;
  while ( GCLK->STATUS.bit.SYNCBUSY == 1 ); // wait for sync

  TcCount16* TC = (TcCount16*) TC3;

  TC->CTRLA.reg &= ~TC_CTRLA_ENABLE;
  while (TC->STATUS.bit.SYNCBUSY == 1); // wait for sync

  // Use the 16-bit timer
  TC->CTRLA.reg |= TC_CTRLA_MODE_COUNT16;
  while (TC->STATUS.bit.SYNCBUSY == 1); // wait for sync

  // Use match mode so that the timer counter resets when the count matches the compare register
  TC->CTRLA.reg |= TC_CTRLA_WAVEGEN_MFRQ;
  while (TC->STATUS.bit.SYNCBUSY == 1); // wait for sync

  // Set prescaler to 1024
  TC->CTRLA.reg |= TC_CTRLA_PRESCALER_DIV1024;
  while (TC->STATUS.bit.SYNCBUSY == 1); // wait for sync

  setTimerFrequency(frequencyHz);

  // Enable the compare interrupt
  TC->INTENSET.reg = 0;
  TC->INTENSET.bit.MC0 = 1;

  NVIC_EnableIRQ(TC3_IRQn);

  TC->CTRLA.reg |= TC_CTRLA_ENABLE;
  while (TC->STATUS.bit.SYNCBUSY == 1); // wait for sync
}
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

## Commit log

2024-04-16 Initial upload V1.1
    [fade4.brd, fade4.sch]
2024-04-18 Fixed MIDI issue on V1 boards
    Reported issue that messages are over 127 when used with a hot USB power supply. Added hard limit to 127.
2024-05-08 Fixed issue with Program Changes not functioning
    Issue with going out of bounds when setting PC as the message. Fixed with bounds checking.
    [fade4.ino]

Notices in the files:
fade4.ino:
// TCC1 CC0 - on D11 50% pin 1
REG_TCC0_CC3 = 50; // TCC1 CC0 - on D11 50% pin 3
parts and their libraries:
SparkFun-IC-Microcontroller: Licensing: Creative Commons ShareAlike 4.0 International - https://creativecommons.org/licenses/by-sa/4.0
